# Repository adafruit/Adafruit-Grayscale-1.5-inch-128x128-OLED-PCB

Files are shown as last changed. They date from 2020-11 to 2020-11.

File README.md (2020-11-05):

## Adafruit Grayscale 1.5" 128x128 OLED Graphic Display - STEMMA QT / Qwiic PCB

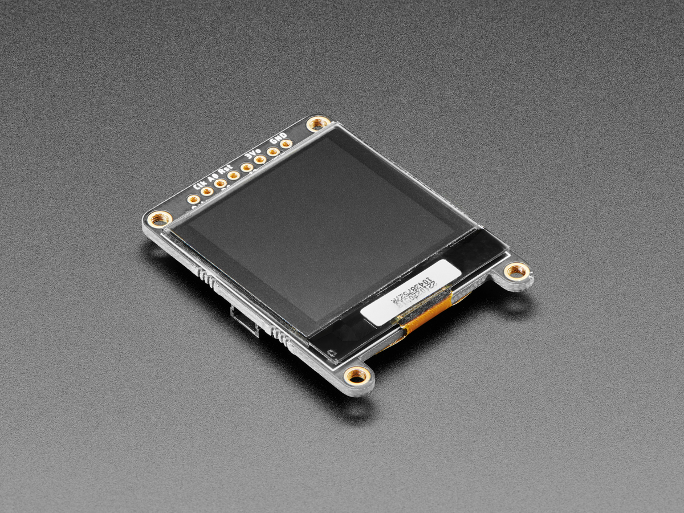
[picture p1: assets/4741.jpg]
<a href="http://www.adafruit.com/products/4741"><br/>
Click here to purchase one from the Adafruit shop</a>

PCB files for the Adafruit Grayscale 1.5" 128x128 OLED Graphic Display - STEMMA QT / Qwiic. 

Format is EagleCAD schematic and board layout
* https://www.adafruit.com/product/4741

### Description

This OLED goes out to all the fans who want more pixels! Normally our 128x64 OLEDs are the biggest ones we've stocked that can use I2C. This one is a whopping 128x128 pixels and it even has an extra bonus - it can do grayscale pixels! Yep, you get the same crispness of a monochome OLED but with 16 levels of grayscale.

This display is a petite 1.5" diagonal , but very readable due to the high contrast of an OLED display. This display is made of 128x128 individual grayscale OLED pixels, each one is turned on or off by the controller chip. Because the display makes its own light, no backlight is required. This reduces the power required to run the OLED and is why the display has such high contrast; we really like these miniature displays for their crispness!

The driver chip, SSD1327 can communicate in two ways: I2C or SPI. The OLED itself require a 3.3V and 12V power supply and 3.3V logic levels for communication. We include a 3.3V regulator and 12V boost converter, and all pins are fully level shifted so you can use with 3V or 5V devices!

If you are using I2C, we've included [SparkFun qwiic](https://www.sparkfun.com/qwiic) compatible [STEMMA QT](https://learn.adafruit.com/introducing-adafruit-stemma-qt) connectors for the I2C bus **so you don't even need to solder!** Plug and play with any board that has a Qwiic or STEMMA QT connector for effortless prototyping and development.

This display, being 16-level (4-bit) grayscale and 128x128 requires 128 * 128 * 4 bits = 8KB of SRAM to buffer. So **you can't use it with a small chip such as the Arduino UNO** (ATmega328 or 32u4). Pick a microcontroller or microcomputer with 16KB+ RAM - a SAMD21, SAMD51, ESP, nRF52, Teensy, etc will do an excellent job. As long as you have I2C or SPI interface available, you're good to go - SPI will be much faster but I2C requires fewer pins.

[We have both Arduino](https://github.com/adafruit/Adafruit_SSD1327) and [CircuitPython support](https://github.com/adafruit/Adafruit_CircuitPython_SSD1327) for this display.

Please note that OLED displays are made of hundreds of...OLEDs! That means each pixel is a little organic LED, and if its kept on for over 1000 hours it'll start to dim. If you want to keep the display uniformly bright, please turn off the display (set the pixels off) when it isn't needed to keep them from dimming.

### License

Adafruit invests time and resources providing this open source design, please support Adafruit and open-source hardware by purchasing products from [Adafruit](https://www.adafruit.com)!

Designed by Limor Fried/Ladyada for Adafruit Industries.

Creative Commons Attribution/Share-Alike, all text above must be included in any redistribution. 
See license.txt for additional details.

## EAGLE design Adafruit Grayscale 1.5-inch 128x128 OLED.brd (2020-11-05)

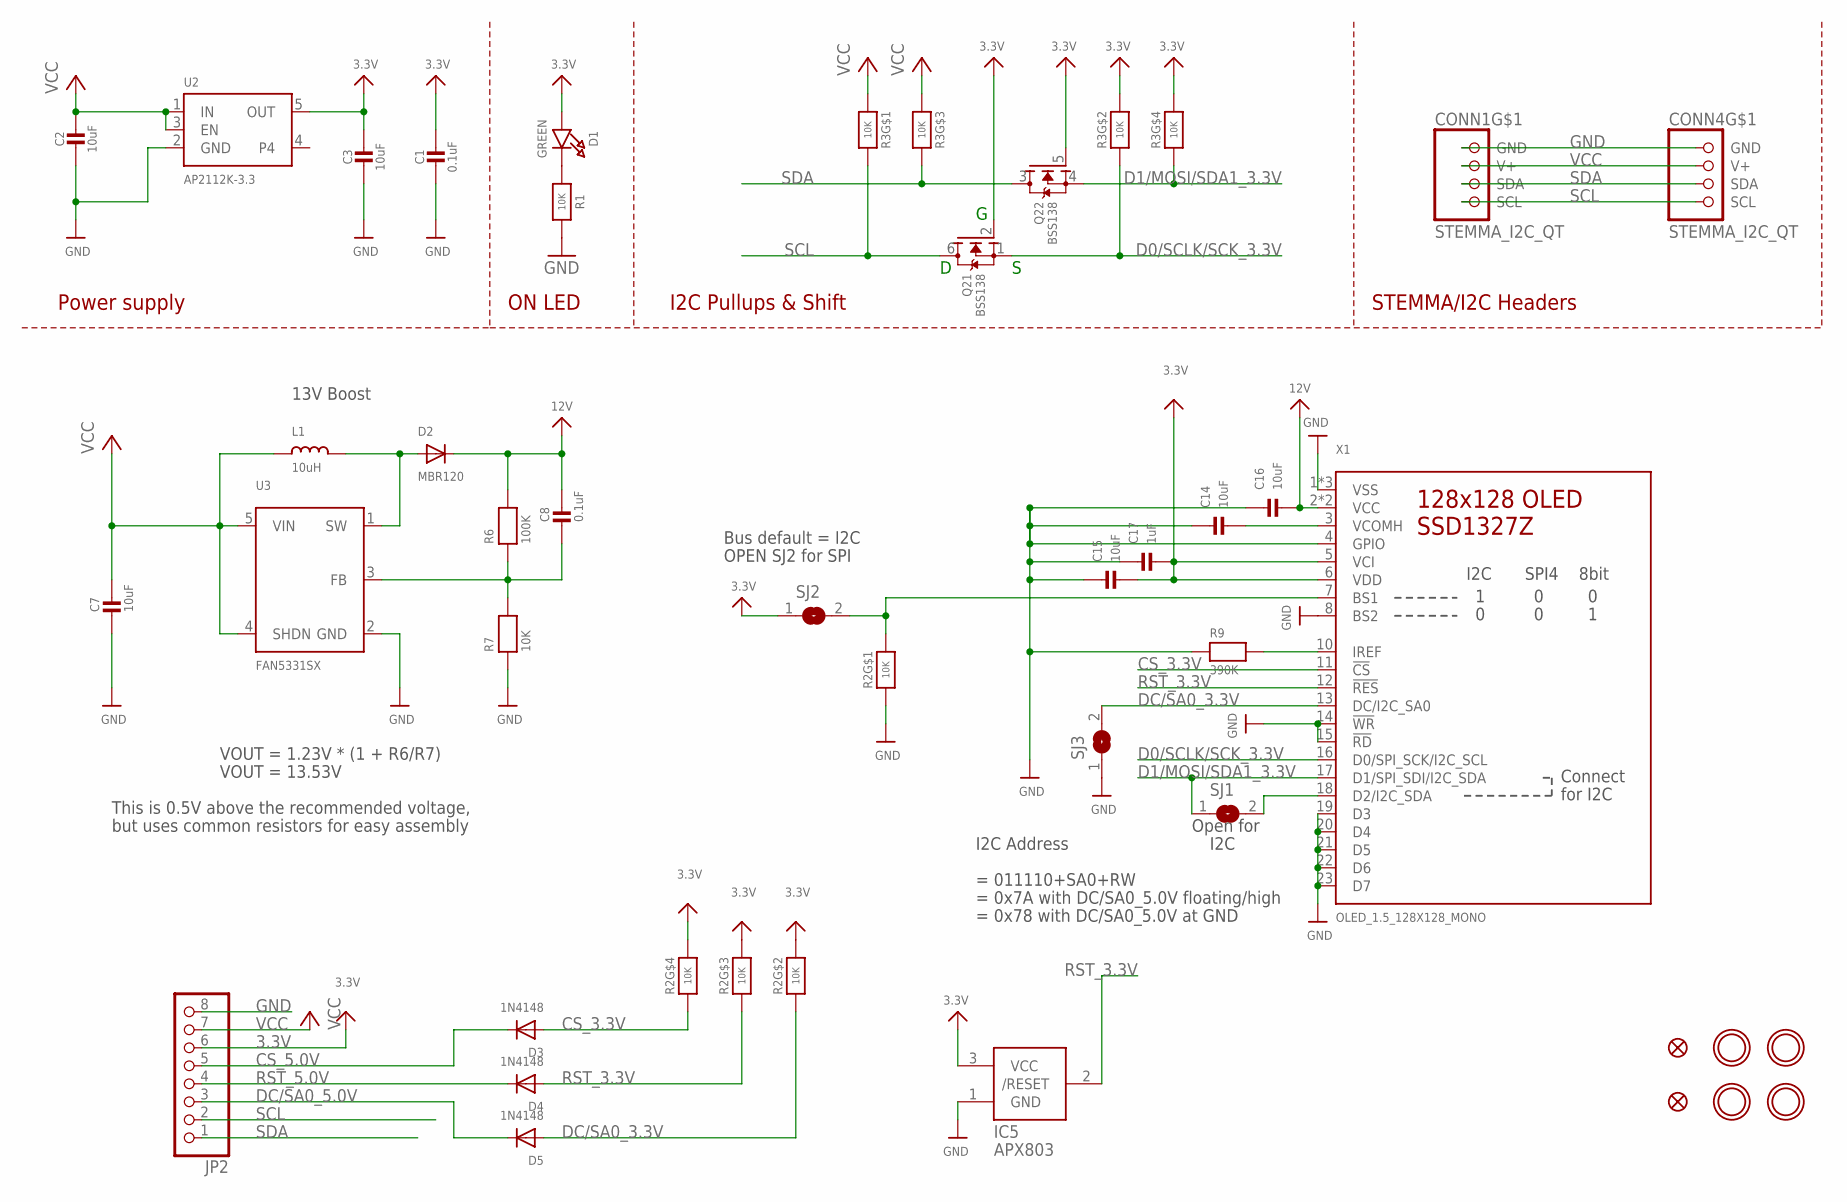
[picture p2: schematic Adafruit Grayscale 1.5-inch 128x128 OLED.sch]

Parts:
C1, C8: 0.1uF; 0603-NO
C2, C3, C7, C14, C15, C16: 10uF; 0805-NO
C17: 1uF; 0603-NO
CONN1, CONN4: STEMMA_I2C_QT; JST_SH4
D1: GREEN; CHIPLED_0603_NOOUTLINE
D2: MBR120; SOD-123
D3, D4, D5: 1N4148; SOD-323
FID3, FID4: FIDUCIAL_1MM
IC5: APX803; SOT23
JP2: HEADER-1X870MIL; 1X08_ROUND_70
L1: 10uH; INDUCTOR_1007
Q2: BSS138; SOT363
R1, R7: 10K; 0603-NO
R2, R3: 10K; RESPACK_4X0603
R6: 100K; 0603-NO
R9: 390K; 0603-NO
SJ1, SJ2: SOLDERJUMPERCLOSED; SOLDERJUMPER_CLOSEDWIRE
SJ3: SOLDERJUMPER; SOLDERJUMPER_ARROW_NOPASTE
U2: AP2112K-3.3; SOT23-5
U3: FAN5331SX; SOT23-5@1
U$1, U$17, U$19, U$21: MOUNTINGHOLE2.5; MOUNTINGHOLE_2.5_PLATED
X1: OLED_1.5_128X128_MONO; OLED_1.5IN_128X128MONO

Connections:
3.3V: C1.1, C3.1, C15.2, C17.2, D1.A, IC5.3 (VCC), JP2.6, Q2.2 (G), Q2.5 (G), R2.5 (2), R2.6 (2), R2.7 (2), R3.2 (1), R3.4 (1), SJ2.1, U2.5 (OUT), X1.5 (VCI), X1.6 (VDD)
12V: C8.1, C16.2, D2.C, R6.2, X1.2 (VCC), X1.24 (VCC)
CS_3.3V: D3.A, R2.4 (1), X1.11 (!CS)
CS_5.0V: D3.C, JP2.5
D0/SCLK/SCK_3.3V: Q2.1 (S), R3.7 (2), X1.16 (D0/SPI_SCK/I2C_SCL)
D1/MOSI/SDA1_3.3V: Q2.4 (S), R3.5 (2), SJ1.1, X1.17 (D1/SPI_SDI/I2C_SDA)
DC/SA0_3.3V: D5.A, R2.2 (1), SJ3.2, X1.13 (DC/I2C_SA0)
DC/SA0_5.0V: D5.C, JP2.3
GND: C1.2, C2.2, C3.2, C7.2, C14.1, C15.1, C16.1, C17.1, CONN1.1 (GND), CONN4.1 (GND), IC5.1 (GND), JP2.8, R1.2, R2.1, R7.1, R9.1, SJ3.1, U2.2 (GND), U3.2 (GND), X1.1 (VSS), X1.4 (GPIO), X1.8 (BS2), X1.9 (VSS), X1.14 (!WR), X1.15 (!RD), X1.19 (D3), X1.20 (D4), X1.21 (D5), X1.22 (D6), X1.23 (D7), X1.25 (VSS)
unnamed: D1.C, R1.1
unnamed: D2.A, L1.P$2 (2), U3.1 (SW)
unnamed: C8.2, R6.1, R7.2, U3.3 (FB)
unnamed: R2.8 (2), SJ2.2, X1.7 (BS1)
unnamed: R9.2, X1.10 (IREF)
unnamed: C14.2, X1.3 (VCOMH)
unnamed: SJ1.2, X1.18 (D2/I2C_SDA)
RST_3.3V: D4.A, IC5.2 (/RESET), R2.3 (1), X1.12 (!RES)
RST_5.0V: D4.C, JP2.4
SCL: CONN1.4 (SCL), CONN4.4 (SCL), JP2.2, Q2.6 (D), R3.8 (2)
SDA: CONN1.3 (SDA), CONN4.3 (SDA), JP2.1, Q2.3 (D), R3.6 (2)
VCC: C2.1, C7.1, CONN1.2 (V+), CONN4.2 (V+), JP2.7, L1.P$1 (1), R3.1, R3.3 (1), U2.1 (IN), U2.3 (EN), U3.4 (SHDN), U3.5 (VIN)

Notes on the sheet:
I2C Pullups & Shift
STEMMA/I2C Headers
ON LED
Power supply
Bus default = I2C
OPEN SJ2 for SPI
= 011110+SA0+RW
= 0x7A with DC/SA0_5.0V floating/high
= 0x78 with DC/SA0_5.0V at GND
I2C Address
Open for
I2C
VOUT = 1.23V * (1 + R6/R7)
VOUT = 13.53V
This is 0.5V above the recommended voltage,
but uses common resistors for easy assembly
13V Boost

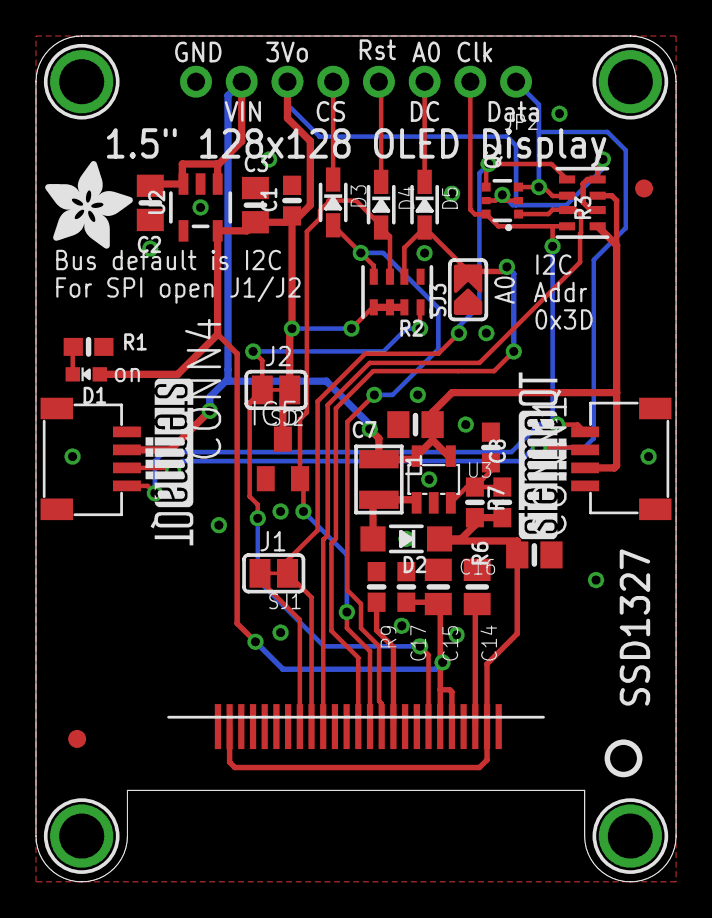
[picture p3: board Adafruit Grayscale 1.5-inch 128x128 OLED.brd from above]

Board: 2 copper layers, 35.6 x 47.0 mm, 42 parts (1 on the bottom side), 21 nets.

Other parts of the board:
U$8: ADAFRUIT_5MM
U$20, U$31: STEMMAQT
U$25: PCBFEAT-REV-040

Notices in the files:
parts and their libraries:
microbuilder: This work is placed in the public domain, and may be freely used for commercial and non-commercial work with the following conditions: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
